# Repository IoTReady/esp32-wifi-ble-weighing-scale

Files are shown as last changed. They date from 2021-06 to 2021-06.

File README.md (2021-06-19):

# ESP32 Weighing Scale

This is a weighing scale designed to share data over Wi-Fi using esp32 WROOM32 module.
For the weighing scale we are using a load cell and measuring the output using a HX711 24-bit ADC designed for weigh scales and industrial control applications to interface directly with a bridge sensor.

The final design and gerber files are available [here](https://github.com/IoTReady/esp32-wifi-ble-weighing-scale/blob/master/design/Single_scale_v3_kicad/single_scale_v3_gerber.zip).

# Circuit Design
## Power Supply
We are using a 3.7V Li-Ion battery for powering this scale. The current rating can be changed depending on the use case. We also have a battery charging circuit on the board, so you don't have to remove the battery for charging it.

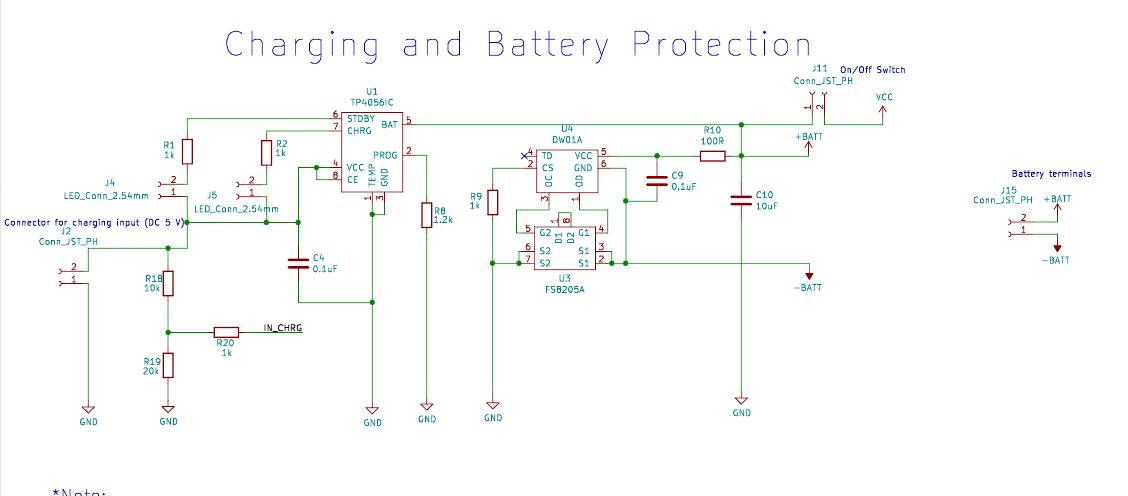
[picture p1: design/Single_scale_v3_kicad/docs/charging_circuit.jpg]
charging circuit Battery Charging Circuit


We use a TP4056 charging IC, as it is easily available and gives a reasonable 1000 mA output current, with 4.2V output voltage for charging the battery. For preventing the battery from over-charging and over-discharging, we use the DW01A protection IC. It is connected with a FS8205A switch IC, which will cut off the battery from the circuit if any fault is detected.

Finally, the 3.7V battery ouput is fed to two voltage regulators to get +5V and +3.3V output voltages as shown below:

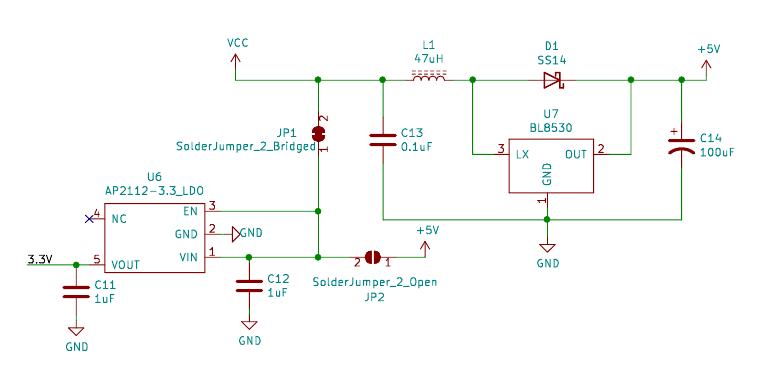
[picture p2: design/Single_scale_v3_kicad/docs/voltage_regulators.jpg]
voltage regs Voltage Regulators


## ADC Circuit
We are using HX711 24-bit ADC IC for converting the analog data from the Load cell. We selected HX711 as it is designed specifically for weighing scales, to interface with brige sensors directly. Load cells are basically bridge sensors.
As shown below the final output is in serial data output form. This is basically a UART output, and there are few digital pin controls.

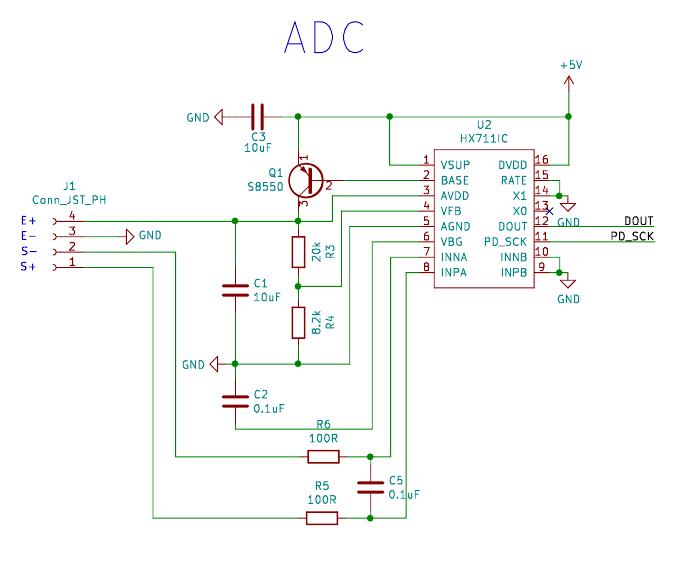
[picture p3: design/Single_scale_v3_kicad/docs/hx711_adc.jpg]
adc HX711 ADC


## ESP32
The brains of our weighing scale, the esp32 wroom32 module is a BLE plus WiFi SoC which collects weight data from the ADC circuit and outputs the final processed data via a digital display and WiFi to the selected servers for maintaing inventories or doing any data analysis.

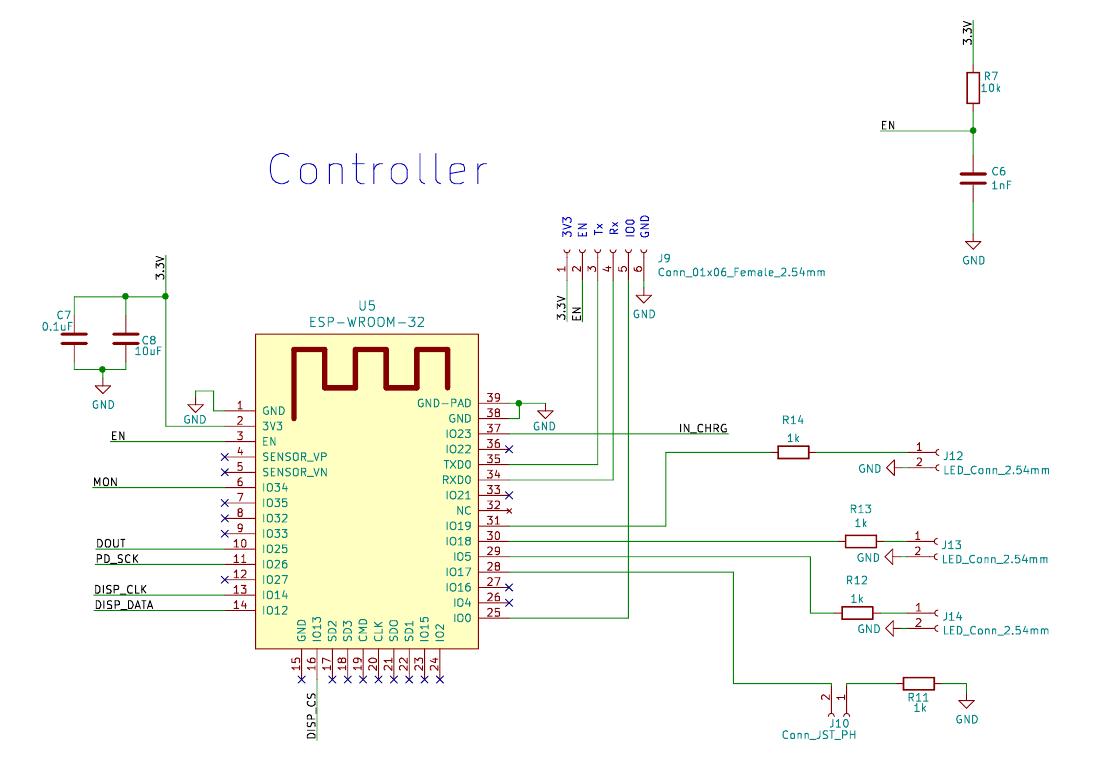
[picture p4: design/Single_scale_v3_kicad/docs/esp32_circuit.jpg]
esp32


# PCB
This is what the final PCB looks like:

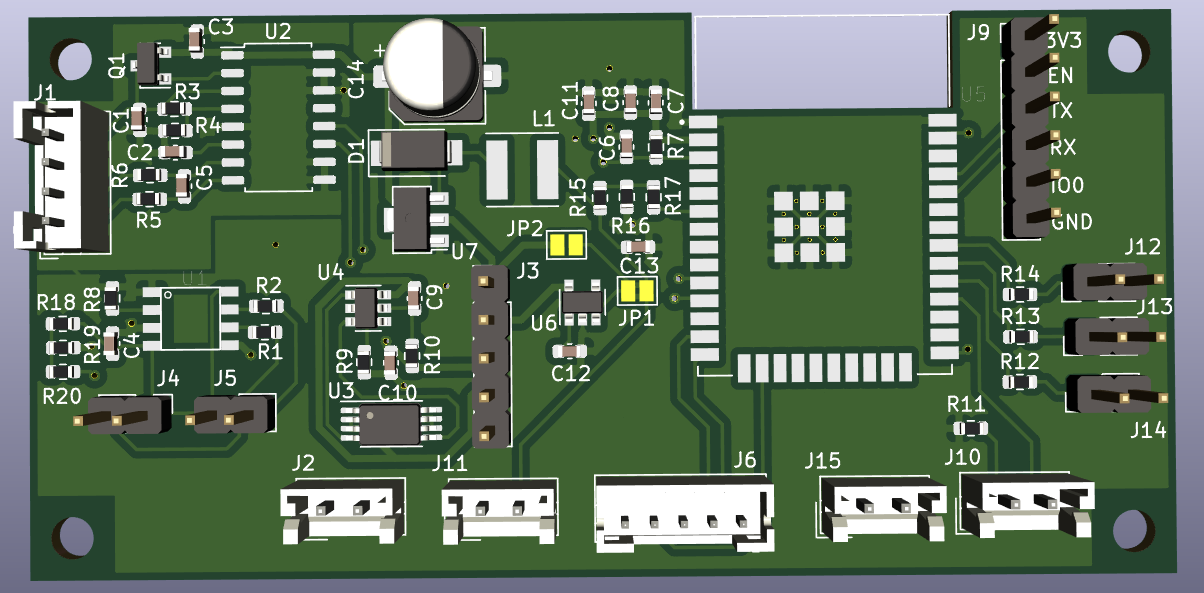
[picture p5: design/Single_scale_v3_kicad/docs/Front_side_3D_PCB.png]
pcb_front


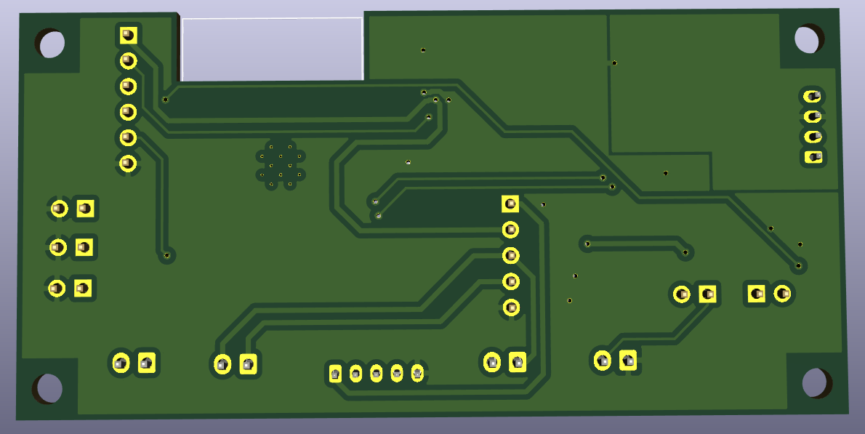
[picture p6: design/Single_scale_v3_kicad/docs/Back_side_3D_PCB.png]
pcb_back


# Firmware

## Features
- 24 bit HX711 as ADC
- Any 4 wire load cell
- BLE communication
- Tare button
- Battery level monitor
- MAX7219 driven 7-segment display
- OTA (to be hosted from local network)
- Console setting of tare value and sensor calibration

### Weight Calculation
The HX711 is a great match for weighing use-cases. The 24 bit ADC is designed specifically for weight measurements and is directly interfaceable with load sensors and weigh bridges. There is no programming needed for the internal registers. All controls to the HX711 are through the pins. The HX711 component handles everything necessary for conversion to calibration. For more details, find the HX711 datasheet [here](https://cdn.sparkfun.com/datasheets/Sensors/ForceFlex/hx711_english.pdf)

### Factors for weight calculation/conversion
There are two major factors to consider in order to get an accurate calculation:
1. Tare Value (OFFSET): In weighment applications it is important to be able to reset the output value to zero if and when needed. In the firmware however, it is particularly important to understand the ADC output at zero. Any value higher or lower than this ADC value would result in positive or negative weight hereafter. Almost all weighing scales will provide a button for the users to return the current weight to zero. This is used to round off any extra weight that needs not be accounted, for example the container. In this application, the tare button has been assigned to GPIO19 on the ESP32.
  The auto-tare feature in the application tares the system at startup, such that the weighing scale always starts with a zero value. This eliminates human error. Make sure that there are no items placed on the platform and even the bottom of the scale is not in contact with any object at the time of starting up the machine until the display shows 0.
  
3. Calibration value (SCALE): The calibration value is the multiplication factor that needs to be multiplied to the ADC output value in order to get the real-time weight out of it in the units needed. This calibration value will be different for all individual load cells, hence it is important that all weighing machines go through a calibration procedure before they are shipped.

This application provides a simple method to set/calculate the above mentioned Tare and Calibration values:
- Start by placing the scale in a stable platform and environment. Please choose an area with minimum air currents and vibration levels.
- Connect your computer to the ESP32 controller's UART0 using an FTDI connector.
- You will need software to access the serial communication happening over the UART lines. For example, [PuTTY](https://www.putty.org/).
- While the program is flashed and running on the ESP32, press 'm' and hit Enter. You will be provided a menu using which you can access the tare and calibration features.
- For calibration, carry out the following steps:
  - You need to select a test value weight. This weight must be within the scale constraint and approximately 50% of the upper capacity. This should also be a known weight that you should possess.
  - Make sure that there are no items placed on the platform and even the bottom of the scale is not in contact with any object.
  - Make sure the console shows 0 weight. If not, press the tare button so the console shows 0.
  - Place the known selected weight on the platform of the weighing scale and view the weight on the console.
  - Follow the instructions to either change the calibration value or select the current selected calibration value if the weight shown on console is correct.
  - Repeat until the weight is correct.
  - Save

### BLE Characteristics:
| Service / Characteristics Name | UUID Handle | Properties | Description |
|---|---|---|---|
| Device State Service | 000000ff-0000-1000-8000-00805f9b34fb | Service | - |
| Weight Data | 0000ff00-0000-1000-8000-00805f9b34fb | Read | Weight in kgs |

| Service / Characteristics Name  | UUID Handle | Properties  | Description | Size | Data Type |
|---|---|---|---|---|---|
| System Settings Service | 000000ee-0000-1000-8000-00805f9b34fb | Service | - | - | - |
| Device ID Characteristic | 0000ee00-0000-1000-8000-00805f9b34fb | Read | Read Device ID | Length: 12 | String |
| WiFi SSID  Characteristic | 0000ee01-0000-1000-8000-00805f9b34fb | Read/Write  | WiFi SSID configured with the device | Max Length: 32  | String |
| WiFi Password Characteristic | 0000ee02-0000-1000-8000-00805f9b34fb | Read/Write  | WiFi Password configured with the device | Max Length: 32  | String |
| OTA IP Characteristic | 0000ee03-0000-1000-8000-00805f9b34fb | Read/Write  | Read/Write the IP of OTA host | Max Length: 100 | String |
| OTA Port Characteristic | 0000ee04-0000-1000-8000-00805f9b34fb | Read/Write  | Read/Write the Port of OTA host server | Max Length: 100 | String |
| OTA Filename Characteristic | 0000ee05-0000-1000-8000-00805f9b34fb | Read/Write  | Read/Write the filename of OTA binary file | Max Length: 100 | String |
| Force OTA Characteristic | 0000ee06-0000-1000-8000-00805f9b34fb | Write | Initiate OTA procedure Value: ‘1’ [0x31] | 1 byte | Unsigned Integer |
| Tare Weight Characteristic | 0000ee07-0000-1000-8000-00805f9b34fb | Write | Cancel OTA procedure within 10 seconds of initiation Value: ‘1’ [0x31] | 1 byte | Unsigned Integer |
| Connect WiFi Characteristic | 0000ee08-0000-1000-8000-00805f9b34fb | Write | Connect to previously configured WiFi credentials. Value: ‘1’ [0x31] | 1 byte | Unsigned Integer |
| Software Version Characteristic | 0000ee09-0000-1000-8000-00805f9b34fb | Read | Read the Software Version in the device | - | String |
# Applications
This weighing scale is designed keeping in mind sharing of data over the internet. So, any application where we need to capture weight of things and maintain a record for any use, we can integrate this device in that system.

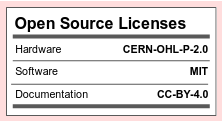
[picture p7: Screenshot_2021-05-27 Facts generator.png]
license_info


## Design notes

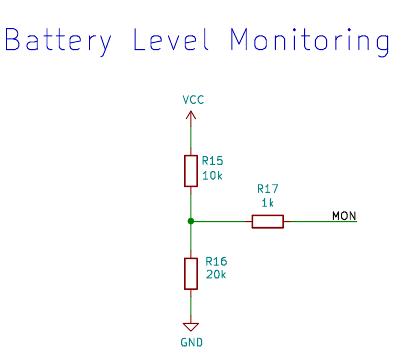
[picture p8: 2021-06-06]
design/Single_scale_v3_kicad/docs/battery_monitor.jpg

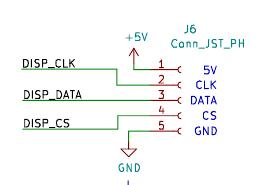
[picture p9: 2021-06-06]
design/Single_scale_v3_kicad/docs/display_connector.jpg

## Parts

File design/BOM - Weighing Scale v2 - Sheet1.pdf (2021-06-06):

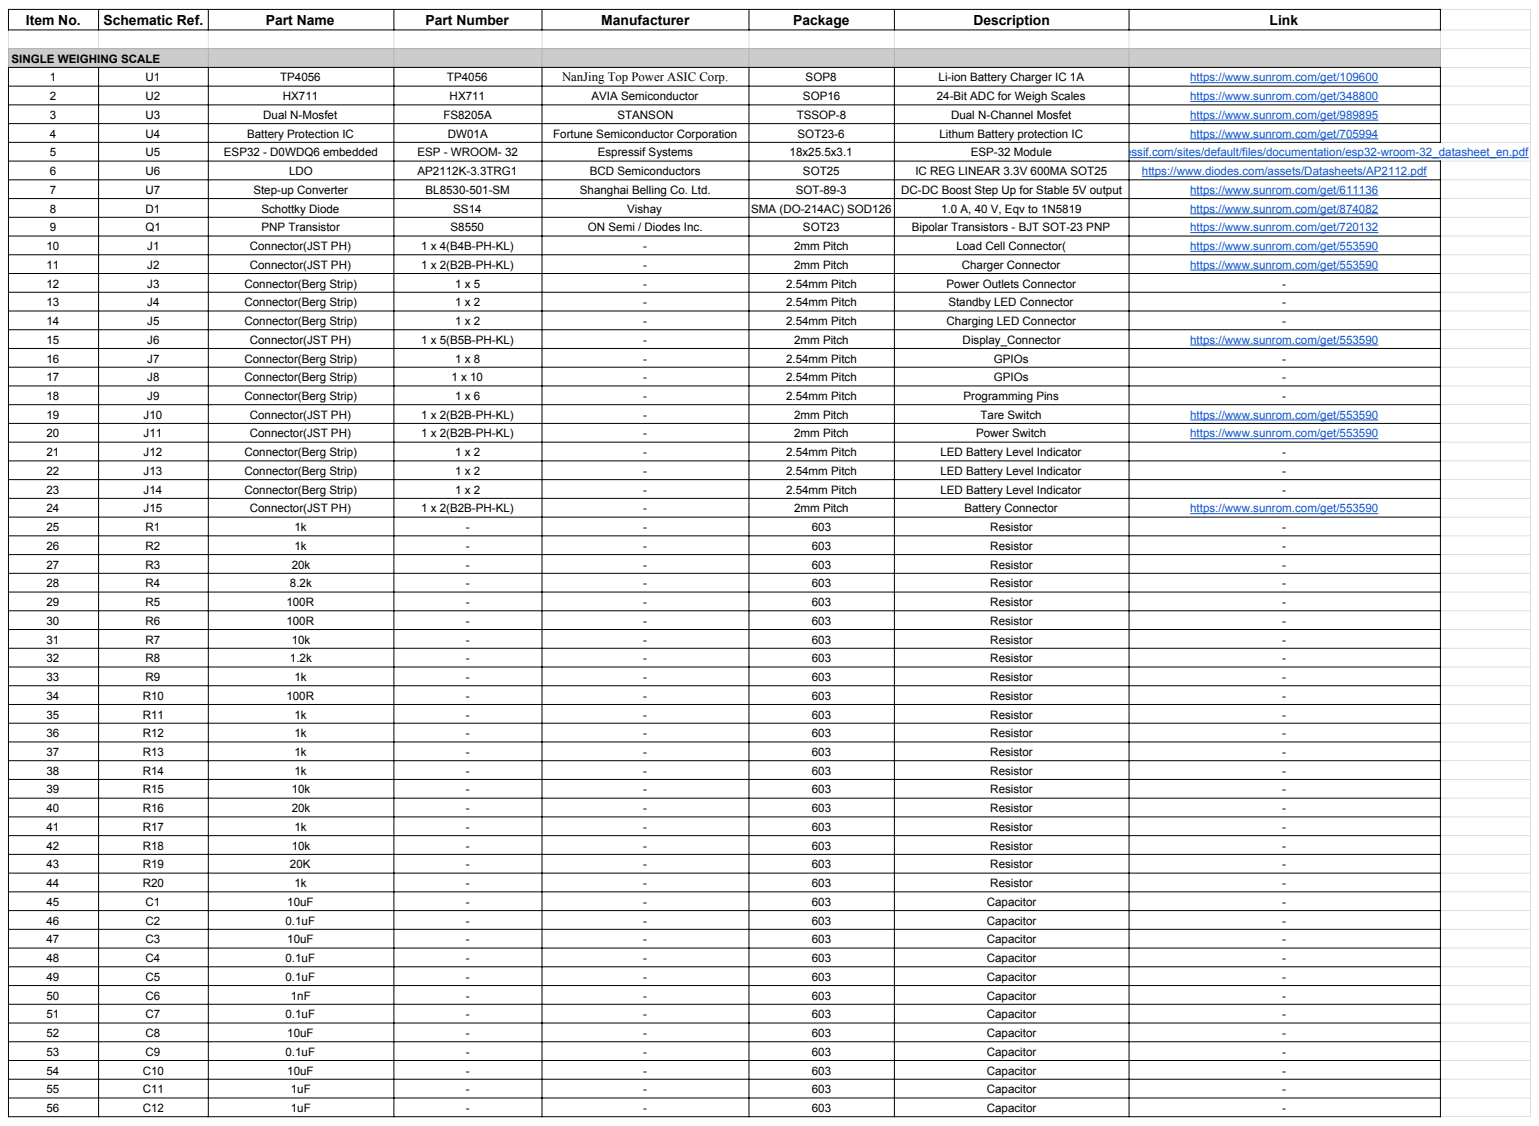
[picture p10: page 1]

1 | U1 | TP4056 | TP4056 | NanJing Top Power ASIC Corp. | SOP8 | Li-ion Battery Charger IC 1A | https://www.sunrom.com/get/109600
2 | U2 | HX711 | HX711 | AVIA Semiconductor | SOP16 | 24-Bit ADC for Weigh Scales | https://www.sunrom.com/get/348800
3 | U3 | Dual N-Mosfet | FS8205A | STANSON | TSSOP-8 | Dual N-Channel Mosfet | https://www.sunrom.com/get/989895
4 | U4 | Battery Protection IC | DW01A | Fortune Semiconductor Corporation | SOT23-6 | Lithum Battery protection IC | https://www.sunrom.com/get/705994

6 | U6 | LDO | AP2112K-3.3TRG1 | BCD Semiconductors | SOT25 | IC REG LINEAR 3.3V 600MA SOT25 | https://www.diodes.com/assets/Datasheets/AP2112.pdf
7 | U7 | Step-up Converter | BL8530-501-SM | Shanghai Belling Co. Ltd. | SOT-89-3 | DC-DC Boost Step Up for Stable 5V output | https://www.sunrom.com/get/611136
8 | D1 | Schottky Diode | SS14 | Vishay | SMA (DO-214AC) SOD126 | 1.0 A, 40 V, Eqv to 1N5819 | https://www.sunrom.com/get/874082
9 | Q1 | PNP Transistor | S8550 | ON Semi / Diodes Inc. | SOT23 | Bipolar Transistors - BJT SOT-23 PNP | https://www.sunrom.com/get/720132
10 | J1 | Connector(JST PH) | 1 x 4(B4B-PH-KL) | - | 2mm Pitch | Load Cell Connector( | https://www.sunrom.com/get/553590
11 | J2 | Connector(JST PH) | 1 x 2(B2B-PH-KL) | - | 2mm Pitch | Charger Connector | https://www.sunrom.com/get/553590
12 | J3 | Connector(Berg Strip) | 1 x 5 | - | 2.54mm Pitch | Power Outlets Connector | -
13 | J4 | Connector(Berg Strip) | 1 x 2 | - | 2.54mm Pitch | Standby LED Connector | -
14 | J5 | Connector(Berg Strip) | 1 x 2 | - | 2.54mm Pitch | Charging LED Connector | -
15 | J6 | Connector(JST PH) | 1 x 5(B5B-PH-KL) | - | 2mm Pitch | Display_Connector | https://www.sunrom.com/get/553590
16 | J7 | Connector(Berg Strip) | 1 x 8 | - | 2.54mm Pitch | GPIOs | -
17 | J8 | Connector(Berg Strip) | 1 x 10 | - | 2.54mm Pitch | GPIOs | -
18 | J9 | Connector(Berg Strip) | 1 x 6 | - | 2.54mm Pitch | Programming Pins | -
19 | J10 | Connector(JST PH) | 1 x 2(B2B-PH-KL) | - | 2mm Pitch | Tare Switch | https://www.sunrom.com/get/553590
20 | J11 | Connector(JST PH) | 1 x 2(B2B-PH-KL) | - | 2mm Pitch | Power Switch | https://www.sunrom.com/get/553590
21 | J12 | Connector(Berg Strip) | 1 x 2 | - | 2.54mm Pitch | LED Battery Level Indicator | -
22 | J13 | Connector(Berg Strip) | 1 x 2 | - | 2.54mm Pitch | LED Battery Level Indicator | -
23 | J14 | Connector(Berg Strip) | 1 x 2 | - | 2.54mm Pitch | LED Battery Level Indicator | -
24 | J15 | Connector(JST PH) | 1 x 2(B2B-PH-KL) | - | 2mm Pitch | Battery Connector | https://www.sunrom.com/get/553590
25 | R1 | 1k | - | - | 603 | Resistor | -
26 | R2 | 1k | - | - | 603 | Resistor | -
27 | R3 | 20k | - | - | 603 | Resistor | -
28 | R4 | 8.2k | - | - | 603 | Resistor | -
29 | R5 | 100R | - | - | 603 | Resistor | -
30 | R6 | 100R | - | - | 603 | Resistor | -
31 | R7 | 10k | - | - | 603 | Resistor | -
32 | R8 | 1.2k | - | - | 603 | Resistor | -
33 | R9 | 1k | - | - | 603 | Resistor | -
34 | R10 | 100R | - | - | 603 | Resistor | -
35 | R11 | 1k | - | - | 603 | Resistor | -
36 | R12 | 1k | - | - | 603 | Resistor | -
37 | R13 | 1k | - | - | 603 | Resistor | -
38 | R14 | 1k | - | - | 603 | Resistor | -
39 | R15 | 10k | - | - | 603 | Resistor | -
40 | R16 | 20k | - | - | 603 | Resistor | -
41 | R17 | 1k | - | - | 603 | Resistor | -
42 | R18 | 10k | - | - | 603 | Resistor | -
43 | R19 | 20K | - | - | 603 | Resistor | -
44 | R20 | 1k | - | - | 603 | Resistor | -
45 | C1 | 10uF | - | - | 603 | Capacitor | -
46 | C2 | 0.1uF | - | - | 603 | Capacitor | -
47 | C3 | 10uF | - | - | 603 | Capacitor | -
48 | C4 | 0.1uF | - | - | 603 | Capacitor | -
49 | C5 | 0.1uF | - | - | 603 | Capacitor | -
50 | C6 | 1nF | - | - | 603 | Capacitor | -
51 | C7 | 0.1uF | - | - | 603 | Capacitor | -
52 | C8 | 10uF | - | - | 603 | Capacitor | -
53 | C9 | 0.1uF | - | - | 603 | Capacitor | -
54 | C10 | 10uF | - | - | 603 | Capacitor | -
55 | C11 | 1uF | - | - | 603 | Capacitor | -
56 | C12 | 1uF | - | - | 603 | Capacitor | -

57 | C13 | 0.1uF | - | - | 603 | Capacitor | -
58 | C14 | 100uF | - | - | 6.3x5.4mm SMD | Aluminium Capacitor | https://www.sunrom.com/get/215444
59 | L1 | 47uH | - | - | 5mm SMD | Wirewound SMD Inductor | https://www.sunrom.com/get/797000
60 | JP1 | SolderJumper_2_Bridged | - | - | - Solder Bridge(Closed) | | -
61 | JP2 | SolderJumper_2_Open | - | - | - Solder Bridge(Open) | | -

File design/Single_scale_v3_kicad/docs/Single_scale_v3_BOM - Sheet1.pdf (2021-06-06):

Sl.no | Reference | Value | Package | Link | Quantity
1 | C1, C3, C8, C10 | 10uF | Capacitor_SMD:C_0603_1608Metric | ~ | 4
2 | C2, C4, C5, C7, C9, C13 | 0.1uF | Capacitor_SMD:C_0603_1608Metric | ~ | 6
3 | C6 | 1nF | Capacitor_SMD:C_0603_1608Metric | ~ | 1
4 | C11, C12 | 1uF | Capacitor_SMD:C_0603_1608Metric | ~ | 2
5 | C14 | 100uF | Capacitor_SMD:CP_Elec_6.3x5.4 | ~ | 1
6 | D1 | SS14 | Diode_SMD:D_SMA | ~ | 1
7 | J1 | Conn_JST_PH | Connector_JST:JST_PH_B4B-PH-K_1x04_P2.00mm_Vertical | ~ | 1
8 | J2, J10, J11, J15 | Conn_JST_PH | Connector_JST:JST_EH_B2B-EH-A_1x02_P2.50mm_Vertical | ~ | 4
9 | J3 | Conn_01x5_Female_2.54mm | Connector_PinHeader_2.54mm:PinHeader_1x05_P2.54mm_Vertical | ~ | 1
10 | J6 | Conn_JST_PH | Connector_JST:JST_PH_B5B-PH-K_1x05_P2.00mm_Vertical | ~ | 1
11 | J9 | Conn_01x06_Female_2.54mm | Connector_PinHeader_2.54mm:PinHeader_1x06_P2.54mm_Vertical | ~ | 1
12 | J4, J5, J12-J14 | LED_Conn_2.54mm | Connector_PinHeader_2.54mm:PinHeader_1x02_P2.54mm_Vertical | ~ | 5
13 | JP1 | SolderJumper_2_Bridged | Jumper:SolderJumper-2_P1.3mm_Bridged2Bar_Pad1.0x1.5mm | ~ | 1
14 | JP2 | SolderJumper_2_Open | Jumper:SolderJumper-2_P1.3mm_Open_Pad1.0x1.5mm | ~ | 1
15 | L1 | 47uH | Inductor_SMD:L_Taiyo-Yuden_MD-5050 | ~ | 1
16 | Q1 | S8550 | single_scale:SOT-23_modified | | 1
17 | R3, R16, R19 | 20k | Resistor_SMD:R_0603_1608Metric | ~ | 3
18 | R4 | 8.2k | Resistor_SMD:R_0603_1608Metric | ~ | 1
19 | R5, R6, R10 | 100R | Resistor_SMD:R_0603_1608Metric | ~ | 3
20 | R7, R15, R18 | 10k | Resistor_SMD:R_0603_1608Metric | ~ | 3
21 | R8 | 1.2k | Resistor_SMD:R_0603_1608Metric | ~ | 1
22 | R1, R2, R9, R11-R14, R17, R20 | 1k | Resistor_SMD:R_0603_1608Metric | ~ | 9
23 | U1 | TP4056IC | single_scale:SOP-8 | | 1
24 | U2 | HX711IC | Package_SO:SOP-16_4.55x10.3mm_P1.27mm | | 1
25 | U3 | FS8205A | Package_SO:TSSOP-8_4.4x3mm_P0.65mm | | 1
26 | U4 | DW01A | Package_TO_SOT_SMD:SOT-23-6 | | 1
27 | U5 | ESP-WROOM-32 | single_scale:MODULE_ESP32-WROOM-32 | | 1
28 | U6 | AP2112-3.3_LDO | Package_TO_SOT_SMD:SOT-23-5 | | 1
29 | U7 | BL8530 | Package_TO_SOT_SMD:SOT-89-3 | | 1

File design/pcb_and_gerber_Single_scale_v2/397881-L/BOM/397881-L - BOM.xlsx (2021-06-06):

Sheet: Sheet1
Item No. | Schematic Ref. | Part Name | Part Number | Manufacturer | Package | Description | Link | Remarks
SINGLE WEIGHING SCALE
1 | U1 | TP4056 | TP4056 | NanJing Top Power ASIC Corp. | SOP8 | Li-ion Battery Charger IC 1A | https://www.sunrom.com/get/109600, Or https://easyeda.com/editor#id=!71fd3f31f7a3ef00a5e0ec6cf54d61e0 | center pad is Not connected to any where ( EX-2 Reply)
2 | U2 | HX711 | HX711 | AVIA Semiconductor | SOP16 | 24-Bit ADC for Weigh Scales | https://www.sunrom.com/get/348800 | Ok as per reply5
3 | U3 | Dual N-Mosfet | FS8205A | STANSON | TSSOP-8 | Dual N-Channel Mosfet | https://www.sunrom.com/get/989895
4 | U4 | Battery Protection IC | DW01A | Fortune Semiconductor Corporation | SOT23-6 | Lithum Battery protection IC | https://www.sunrom.com/get/705994
5 | U5 | ESP32 - D0WDQ6 embedded | ESP - WROOM- 32 | Espressif Systems | 18x25.5x3.1 | ESP-32 Module | https://www.espressif.com/sites/default/files/documentation/esp32-wroom-32_datasheet_en.pdf
6 | U6 | LDO | AP2112K-3.3TRG1 | BCD Semiconductors | SOT25 | IC REG LINEAR 3.3V 600MA SOT25 | https://www.diodes.com/assets/Datasheets/AP2112.pdf
7 | U7 | Step-up Converter | BL8530-501-SM | Shanghai Belling Co. Ltd. | SOT-89-3 | DC-DC Boost Step Up for Stable 5V output | https://www.sunrom.com/get/611136
8 | D1 | Schottky Diode | SS14 | Vishay | SMA (DO-214AC) SOD126 | 1.0 A, 40 V, Eqv to 1N5819 | https://www.sunrom.com/get/874082
9 | Q1 | PNP Transistor | S8550 | ON Semi / Diodes Inc. | SOT23 | Bipolar Transistors - BJT SOT-23 PNP | https://www.sunrom.com/get/720132
10 | J1 | Connector(JST PH) | 1 x 4(S4B-PH-K-S(LF)(SN)) | JST PH connectors(right angle)--EX-3 Reply | 2mm Pitch | Load Cell Connector( | https://www.digikey.in/product-detail/en/jst-sales-america-inc/S2B-PH-K-S-LF-SN/455-1719-ND/926626
11 | J2 | Connector(JST PH) | 1 x 2(S2B-PH-K-S(LF)(SN)) | JST PH connectors(right angle)--EX-3 Reply | 2mm Pitch | Charger Connector | https://www.digikey.in/product-detail/en/jst-sales-america-inc/S2B-PH-K-S-LF-SN/455-1719-ND/926626
12 | J3 | Connector(Berg Strip) | 1 x 5 | - | 2.54mm Pitch | Power Outlets Connector | -
13 | J4 | Connector(Berg Strip) | 1 x 2 | - | 2.54mm Pitch | Standby LED Connector | -
14 | J5 | Connector(Berg Strip) | 1 x 2 | - | 2.54mm Pitch | Charging LED Connector | -
15 | J6 | Connector(JST PH) | 1 x 5(S5B-PH-K-S(LF)(SN)) | JST PH connectors(right angle)--EX-3 Reply | 2mm Pitch | Display_Connector | https://www.digikey.in/product-detail/en/jst-sales-america-inc/S2B-PH-K-S-LF-SN/455-1719-ND/926626
16 | J7 | Connector(Berg Strip) | 1 x 8 | EX-1 Reply | 2.54mm Pitch | GPIOs | -
17 | J8 | Connector(Berg Strip) | 1 x 10 | - | 2.54mm Pitch | GPIOs | -
18 | J9 | Connector(Berg Strip) | 1 x 6 | - | 2.54mm Pitch | Programming Pins | -
19 | J10 | Connector(JST PH) | 1 x 2(S2B-PH-K-S(LF)(SN)) | JST PH connectors(right angle)--EX-3 Reply | 2mm Pitch | Tare Switch | https://www.digikey.in/product-detail/en/jst-sales-america-inc/S2B-PH-K-S-LF-SN/455-1719-ND/926626
20 | J11 | Connector(JST PH) | 1 x 2(S2B-PH-K-S(LF)(SN)) | JST PH connectors(right angle)--EX-3 Reply | 2mm Pitch | Power Switch | https://www.digikey.in/product-detail/en/jst-sales-america-inc/S2B-PH-K-S-LF-SN/455-1719-ND/926626
21 | J12 | Connector(Berg Strip) | 1 x 2 | - | 2.54mm Pitch | LED Battery Level Indicator | -
22 | J13 | Connector(Berg Strip) | 1 x 2 | - | 2.54mm Pitch | LED Battery Level Indicator | -
23 | J14 | Connector(Berg Strip) | 1 x 2 | - | 2.54mm Pitch | LED Battery Level Indicator
24 | J15 | Connector(JST PH) | 1 x 2(S2B-PH-K-S(LF)(SN)) | JST PH connectors(right angle)--EX-3 Reply | 2mm Pitch | Battery Connector | https://www.digikey.in/product-detail/en/jst-sales-america-inc/S2B-PH-K-S-LF-SN/455-1719-ND/926626
25 | R1 | 1k | - | - | 603 | Resistor | -
26 | R2 | 1k | - | - | 603 | Resistor | -
27 | R3 | what's new around me | - | - | 603 | Resistor | -
28 | R4 | 8.2k | - | - | 603 | Resistor | -
29 | R5 | 100R | - | - | 603 | Resistor | -
30 | R6 | 100R | - | - | 603 | Resistor | -
31 | R7 | 10k | - | - | 603 | Resistor | -
32 | R8 | 1.2k | - | - | 603 | Resistor | -
33 | R9 | 1k | - | - | 603 | Resistor | -
34 | R10 | 100R | - | - | 603 | Resistor | -
35 | R11 | 1k | - | - | 603 | Resistor | -
36 | R12 | 1k | - | - | 603 | Resistor | -
37 | R13 | 1k | - | - | 603 | Resistor | -
38 | R14 | 1k | - | - | 603 | Resistor | -
39 | R15 | 10k | - | - | 603 | Resistor | -
40 | R16 | 20k | - | - | 603 | Resistor | -
41 | R17 | 1k | - | - | 603 | Resistor | -
42 | R18 | 10k | - | - | 603 | Resistor | -
43 | R19 | 20K | - | - | 603 | Resistor | -
44 | R20 | 1k | - | - | 603 | Resistor | -
45 | C1 | 10uF | - | - | 603 | Capacitor | -
46 | C2 | 0.1uF | - | - | 603 | Capacitor | -
47 | C3 | 10uF | - | - | 603 | Capacitor | -
48 | C4 | 0.1uF | - | - | 603 | Capacitor | -
49 | C5 | 0.1uF | - | - | 603 | Capacitor | -
50 | C6 | 1nF | - | - | 603 | Capacitor | -
51 | C7 | 0.1uF | - | - | 603 | Capacitor | -
52 | C8 | 10uF | - | - | 603 | Capacitor | -
53 | C9 | 0.1uF | - | - | 603 | Capacitor | -
54 | C10 | 10uF | - | - | 603 | Capacitor | -
55 | C11 | 1uF | - | - | 603 | Capacitor | -
56 | C12 | 1uF | - | - | 603 | Capacitor | -
57 | C13 | 0.1uF | - | - | 603 | Capacitor | -
58 | C14 | 100uF | - | - | 6.3x5.4mm SMD | Aluminium Capacitor | https://www.sunrom.com/get/215444
59 | L1 | 47uH | - | - | 5mm SMD | Wirewound SMD Inductor | https://www.sunrom.com/get/797000
60 | R21 |  | - | EX-1 Reply | 603 |  | -
61 | R22 |  | - | EX-1 Reply | 603 |  | -

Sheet: Quantity
Part Name | Qty / Board | Purchase (Y/N)
TP4056 | 1 | Sunrom
HX711 | 1 | Sunrom
Dual N-Mosfet | 1 | Sunrom
Battery Protection IC | 1 | Sunrom
ESP32 - D0WDQ6 embedded | 1 | Y
LDO | 1 | N
Step-up Converter | 1 | Sunrom
Schottky Diode | 1 | Sunrom
PNP Transistor | 1 | N
1k | 7 | TBD
20k | 1 | TBD
8.2k | 1 | TBD
100R | 3 | TBD
10k | 4 | TBD
1.2k | 1 | TBD
10uF | 4 | TBD
0.1uF | 5 | TBD
1nF | 1 | TBD
1uF | 2 | TBD
100uF | 1 | Sunrom
100uF (TANTALUM) | 1 | Sunrom
22uH | 1 | Sunrom

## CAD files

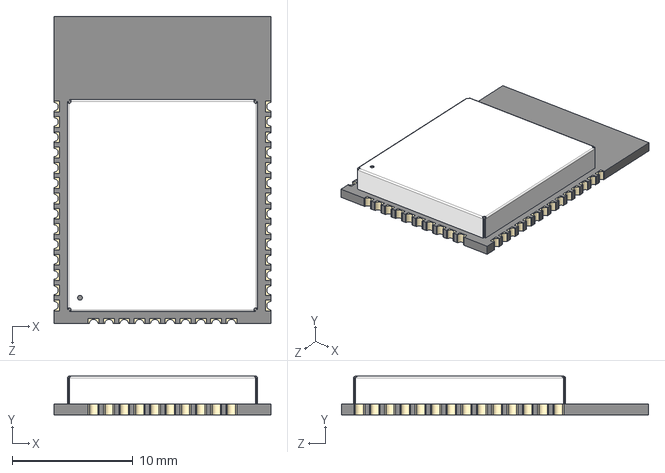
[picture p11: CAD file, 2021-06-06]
design/Single_scale_v3_kicad/kicad.lib/ESP32-WROOM-32.step
18.0 x 3.20 x 25.5 mm

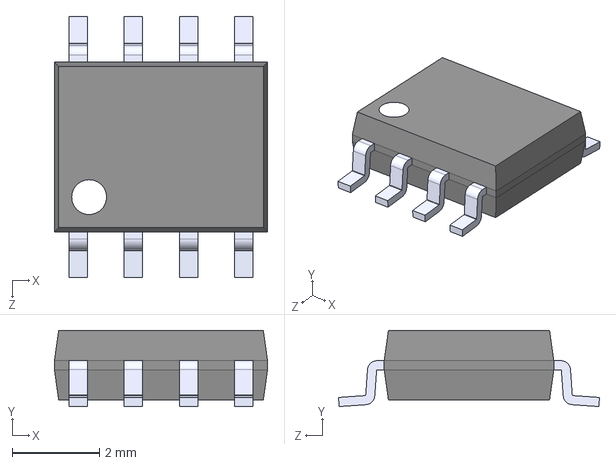
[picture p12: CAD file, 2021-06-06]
design/Single_scale_v3_kicad/kicad.lib/TP4056.step
4.90 x 1.75 x 6.00 mm

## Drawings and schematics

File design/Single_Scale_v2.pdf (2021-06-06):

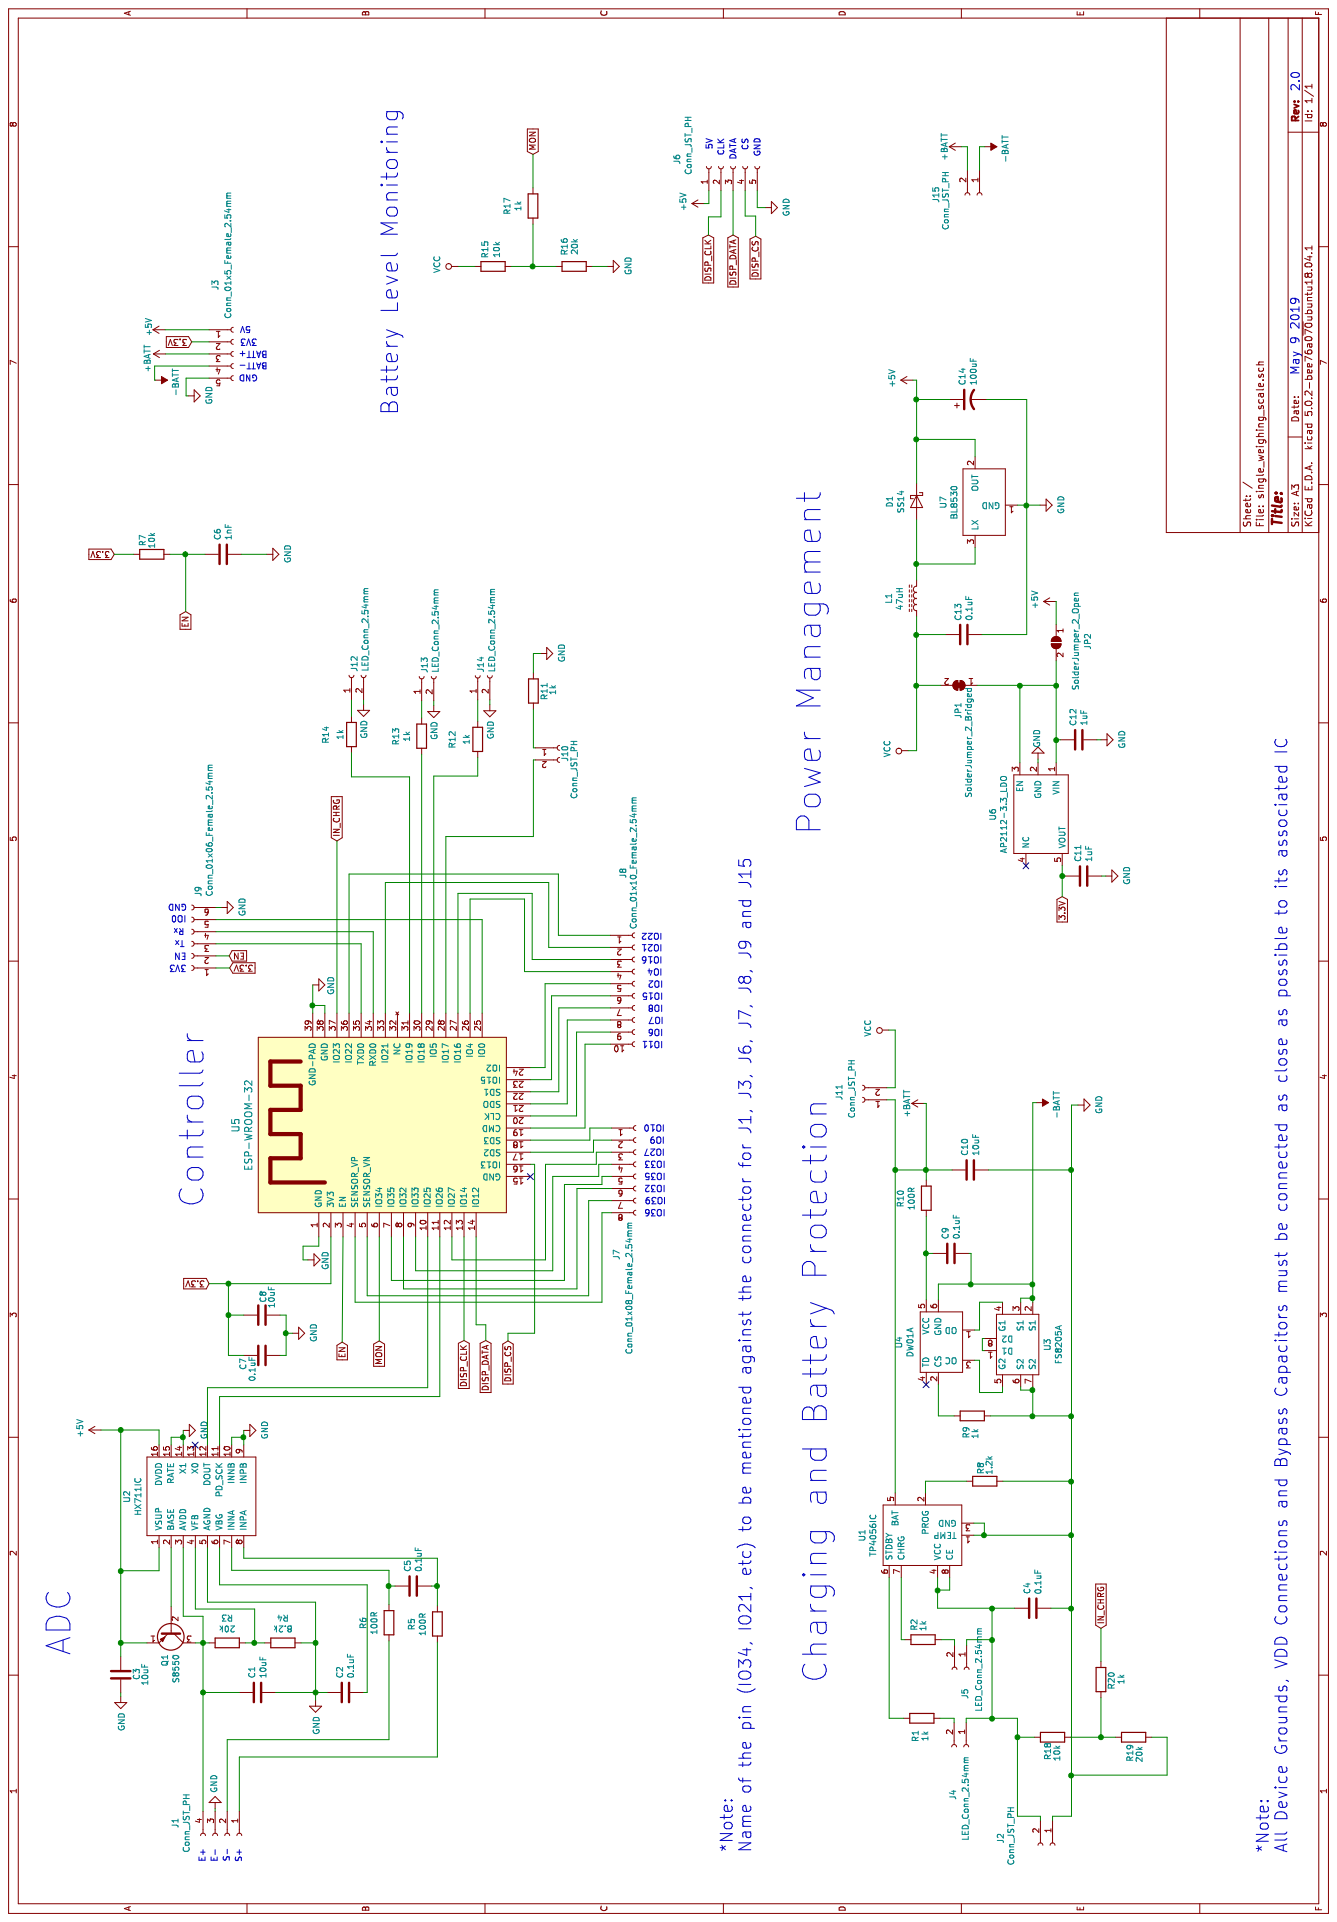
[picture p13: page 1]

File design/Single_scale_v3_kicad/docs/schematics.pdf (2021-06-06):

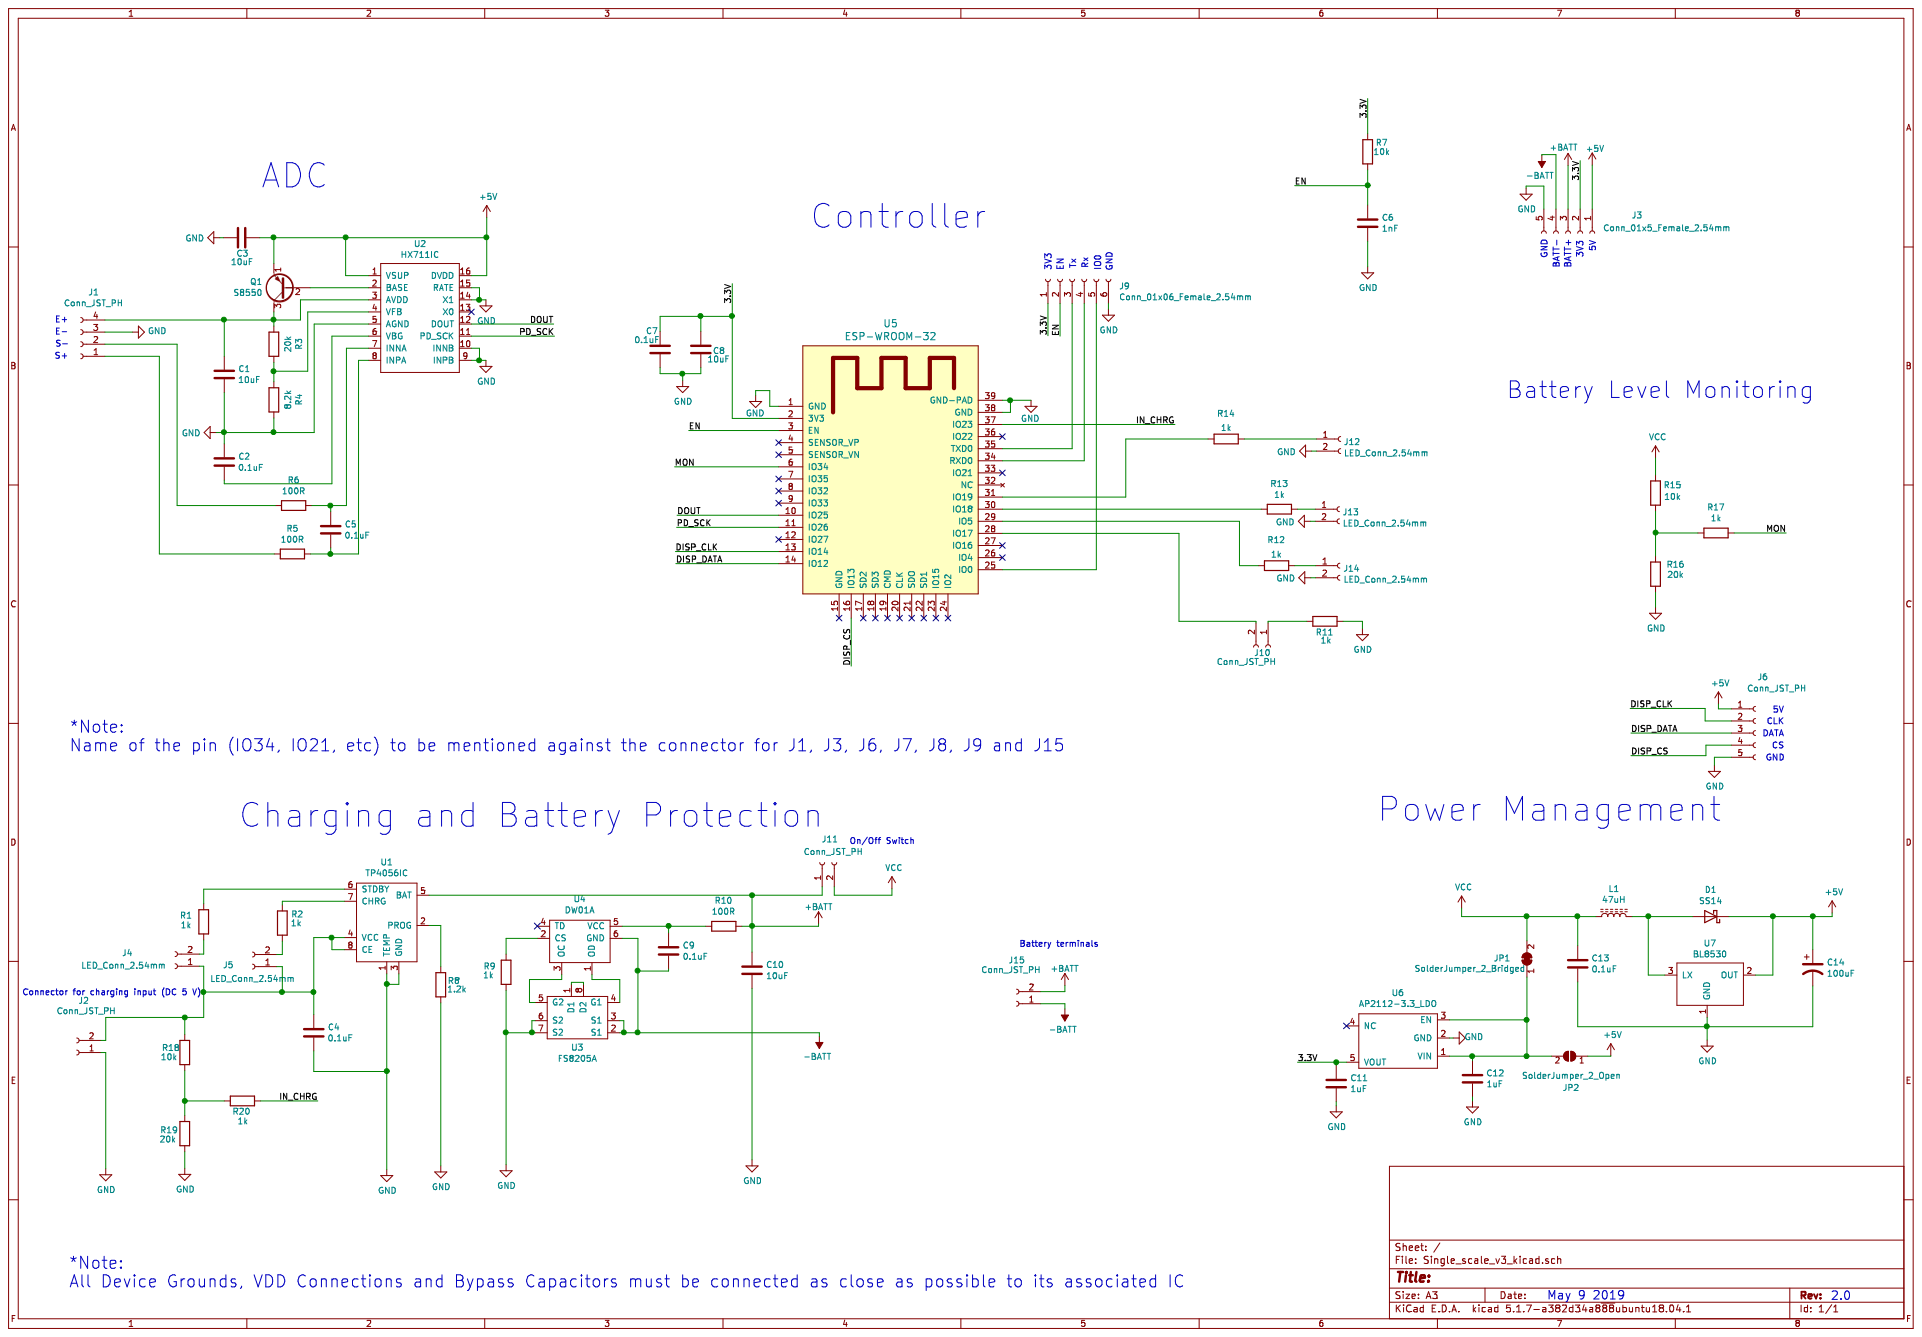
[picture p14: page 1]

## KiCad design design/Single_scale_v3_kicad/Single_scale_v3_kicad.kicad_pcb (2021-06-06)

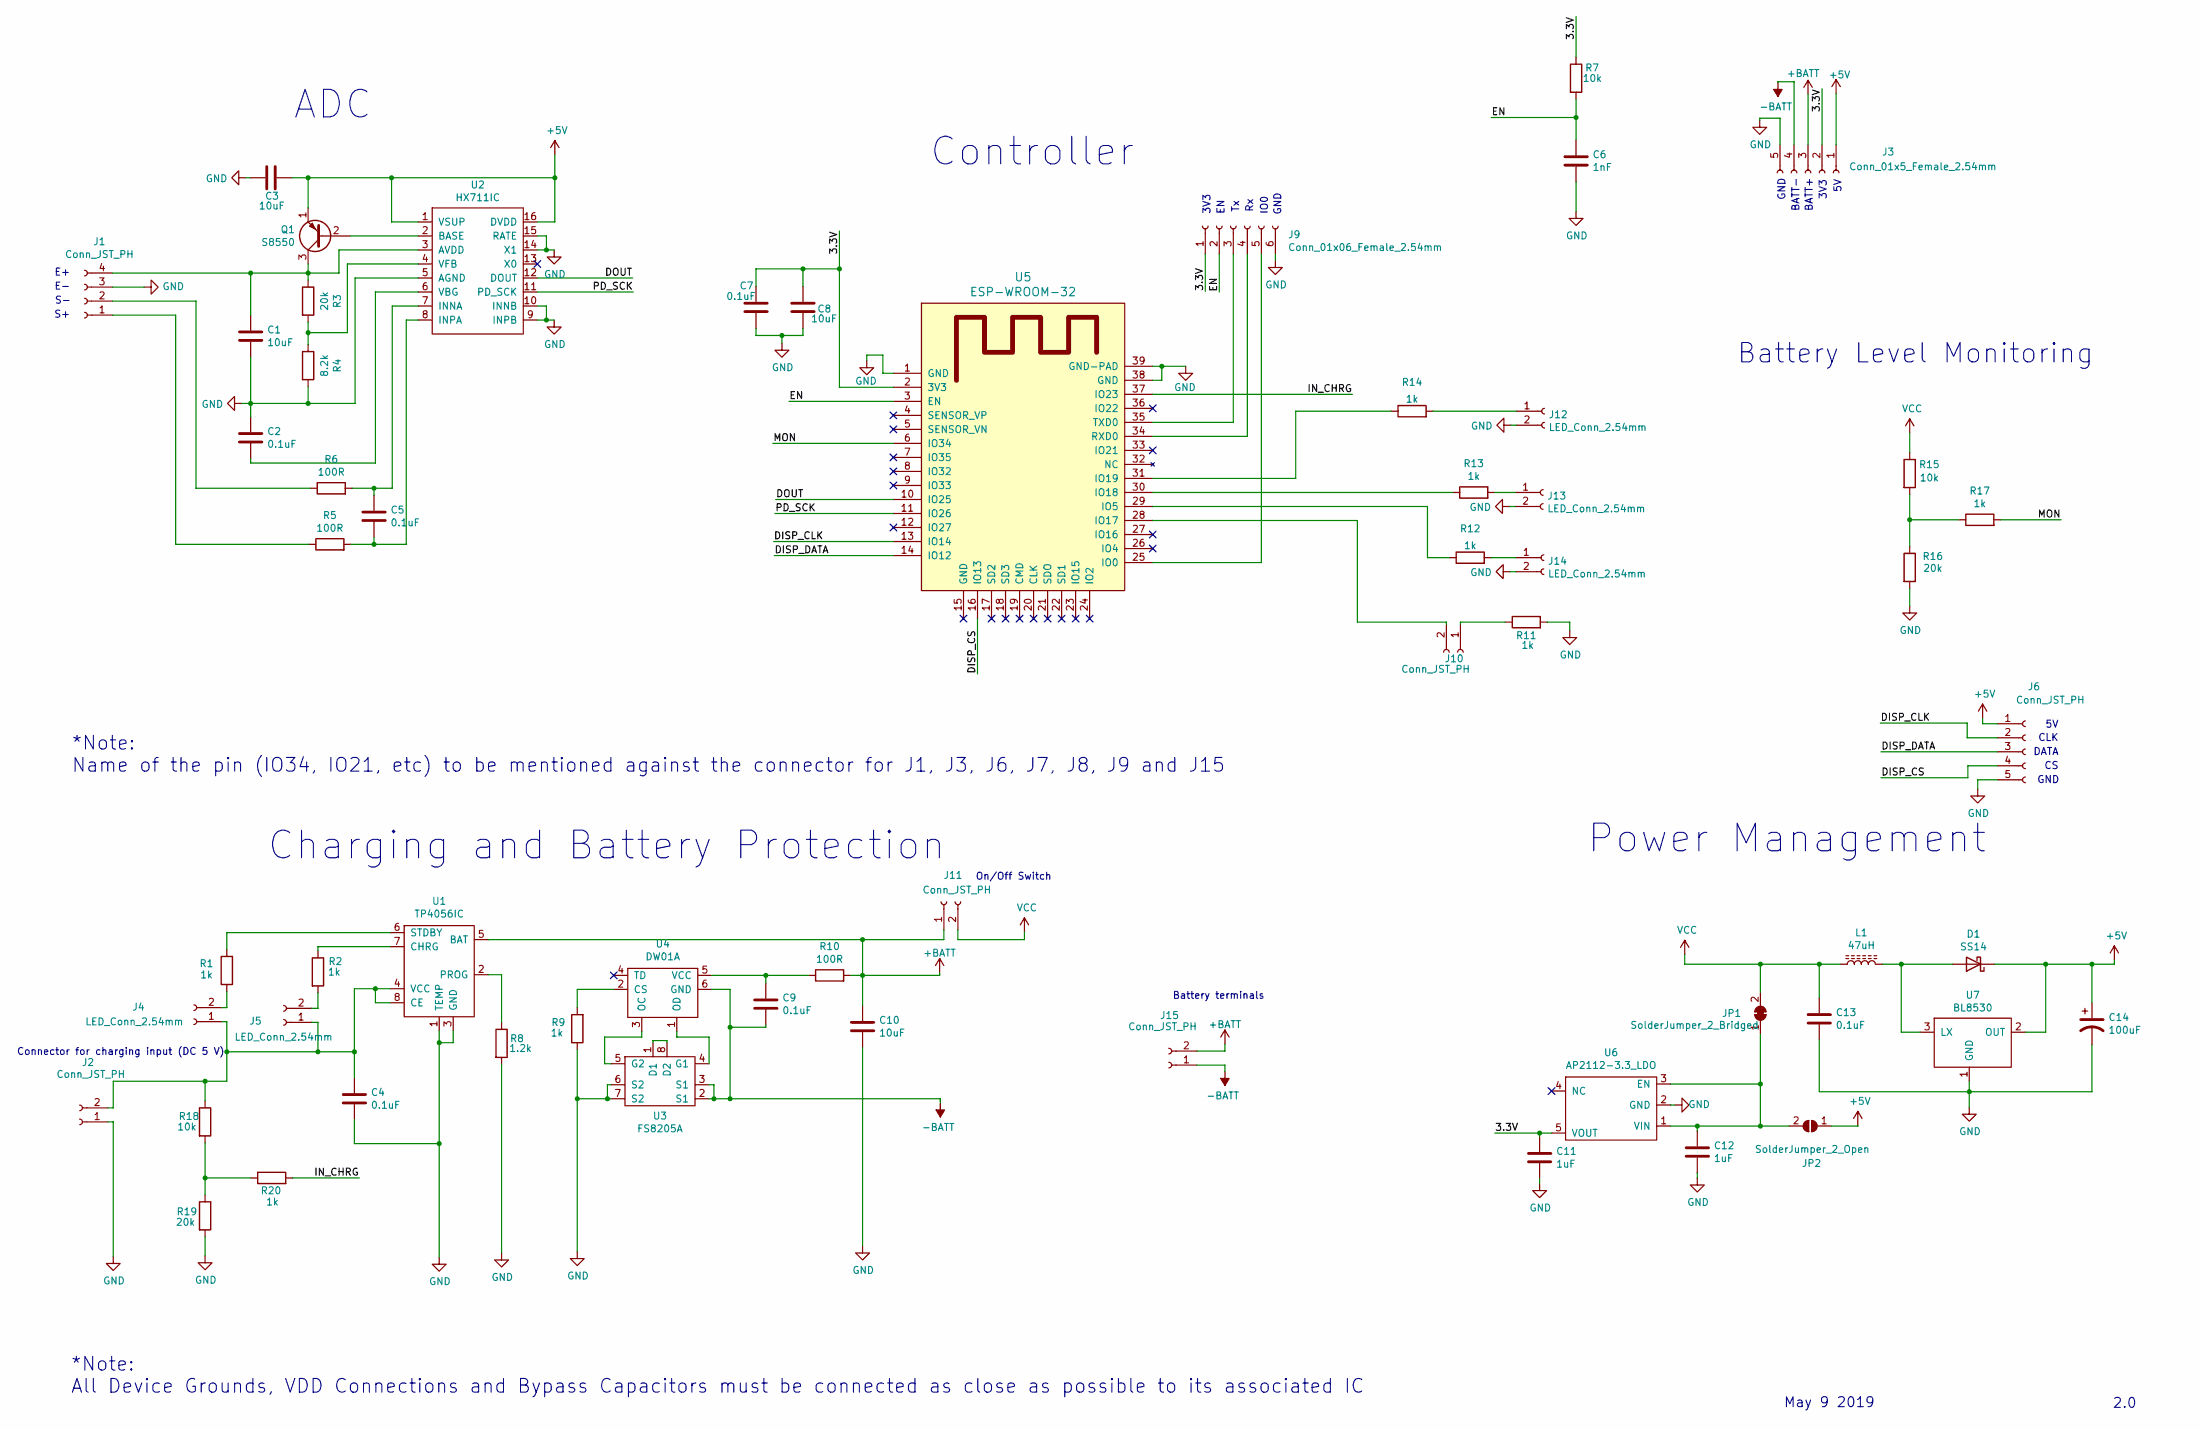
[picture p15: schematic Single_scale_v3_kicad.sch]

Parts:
C1, C3, C8, C10: 10uF; C_0603_1608Metric
C2, C4, C5, C7, C9, C13: 0.1uF; C_0603_1608Metric
C6: 1nF; C_0603_1608Metric
C11, C12: 1uF; C_0603_1608Metric
C14: 100uF; CP_Elec_6.3x5.4
D1: SS14; D_SMA
J1: Conn_JST_PH; JST_PH_B4B-PH-K_1x04_P2.00mm_Vertical
J2, J10, J11, J15: Conn_JST_PH; JST_EH_B2B-EH-A_1x02_P2.50mm_Vertical
J3: Conn_01x5_Female_2.54mm; PinHeader_1x05_P2.54mm_Vertical
J4, J5, J12, J13, J14: LED_Conn_2.54mm; PinHeader_1x02_P2.54mm_Vertical
J6: Conn_JST_PH; JST_PH_B5B-PH-K_1x05_P2.00mm_Vertical
J9: Conn_01x06_Female_2.54mm; PinHeader_1x06_P2.54mm_Vertical
JP1: SolderJumper_2_Bridged; SolderJumper-2_P1.3mm_Bridged2Bar_Pad1.0x1.5mm
JP2: SolderJumper_2_Open; SolderJumper-2_P1.3mm_Open_Pad1.0x1.5mm
L1: 47uH; L_Taiyo-Yuden_MD-5050
Q1: S8550; SOT-23_modified
R1, R2, R9, R11, R12, R13, R14, R17, R20: 1k; R_0603_1608Metric
R3, R16, R19: 20k; R_0603_1608Metric
R4: 8.2k; R_0603_1608Metric
R5, R6, R10: 100R; R_0603_1608Metric
R7, R15, R18: 10k; R_0603_1608Metric
R8: 1.2k; R_0603_1608Metric
U1: TP4056IC; SOP-8
U2: HX711IC; SOP-16_4.55x10.3mm_P1.27mm
U3: FS8205A; TSSOP-8_4.4x3mm_P0.65mm
U4: DW01A; SOT-23-6
U5: ESP-WROOM-32; MODULE_ESP32-WROOM-32
U6: AP2112-3.3_LDO; SOT-23-5
U7: BL8530; SOT-89-3

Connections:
+5V: C3.1, C14.1, D1.1 (K), J3.1, J6.1, JP2.1 (A), Q1.1 (E), U2.1 (VSUP), U2.16 (DVDD), U7.2 (OUT)
+BATT: C10.1, J3.3, J11.1, J15.2, R10.2, U1.5 (BAT)
-BATT: C9.2, J3.4, J15.1, U3.2 (S1), U3.3 (S1), U4.6 (GND)
/3.3V: C7.1, C8.1, C11.1, J3.2, J9.1, R7.1, U5.2 (3V3), U6.5 (VOUT)
/DISP_CLK: J6.2, U5.13 (IO14)
/DISP_CS: J6.4, U5.16 (IO13)
/DISP_DATA: J6.3, U5.14 (IO12)
/DOUT: U2.12 (DOUT), U5.10 (IO25)
/EN: C6.1, J9.2, R7.2, U5.3 (EN)
/IN_CHRG: R20.2, U5.37 (IO23)
/MON: R17.2, U5.6 (IO34)
/PD_SCK: U2.11 (PD_SCK), U5.11 (IO26)
GND: C1.2, C2.1, C3.2, C4.2, C6.2, C7.2, C8.2, C10.2, C11.2, C12.2, C13.2, C14.2, J1.3, J2.1, J3.5, J6.5, J9.6, J12.2, J13.2, J14.2, R4.2, R8.2, R9.1, R11.2, R16.2, R19.2, U1.1 (TEMP), U1.3 (GND), U2.5 (AGND), U2.9 (INPB), U2.10 (INNB), U2.14 (X1), U2.15 (RATE), U3.6 (S2), U3.7 (S2), U5.1 (GND), U5.38 (GND), U5.39 (GND-PAD), U6.2 (GND), U7.1 (GND)
unnamed: C1.1, J1.4, Q1.3 (C), R3.1, U2.3 (AVDD)
unnamed: C2.2, U2.6 (VBG)
unnamed: C4.1, J2.2, J4.1, J5.1, R18.1, U1.4 (VCC), U1.8 (CE)
unnamed: C5.1, R6.2, U2.7 (INNA)
unnamed: C5.2, R5.2, U2.8 (INPA)
unnamed: C9.1, R10.1, U4.5 (VCC)
unnamed: C12.1, JP1.1 (A), JP2.2 (B), U6.1 (VIN), U6.3 (EN)
unnamed: D1.2 (A), L1.2, U7.3 (LX)
unnamed: J1.1, R5.1
unnamed: J1.2, R6.1
unnamed: J4.2, R1.1
unnamed: J5.2, R2.2
unnamed: J9.3, U5.35 (TXD0)
unnamed: J9.4, U5.34 (RXD0)
unnamed: J9.5, U5.25 (IO0)
unnamed: J10.1, R11.1
unnamed: J10.2, U5.28 (IO17)
unnamed: J12.1, R14.2
unnamed: J13.1, R13.2
unnamed: J14.1, R12.2
unnamed: Q1.2 (B), U2.2 (BASE)
unnamed: R1.2, U1.6 (STDBY)
unnamed: R2.1, U1.7 (CHRG)
unnamed: R3.2, R4.1, U2.4 (VFB)
unnamed: R8.1, U1.2 (PROG)
unnamed: R9.2, U4.2 (CS)
unnamed: R12.1, U5.29 (IO5)
unnamed: R13.1, U5.30 (IO18)
unnamed: R14.1, U5.31 (IO19)
unnamed: R15.2, R16.1, R17.1
unnamed: R18.2, R19.1, R20.1
unnamed: U3.1 (D1), U3.8 (D2)
unnamed: U3.4 (G1), U4.1 (OD)
unnamed: U3.5 (G2), U4.3 (OC)
VCC: C13.1, J11.2, JP1.2 (B), L1.1, R15.1

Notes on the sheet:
Charging and Battery Protection
Power Management
ADC
Battery Level Monitoring
Controller
May 9 2019
2.0
*Note: All Device Grounds, VDD Connections and Bypass Capacitors must be connected as close as possible to its associated IC
*Note: Name of the pin (IO34, IO21, etc) to be mentioned against the connector for J1, J3, J6, J7, J8, J9 and J15
GND
BATT-
BATT+
3V3
IO0
DATA
CLK
Connector for charging input (DC 5 V)
Battery terminals
On/Off Switch

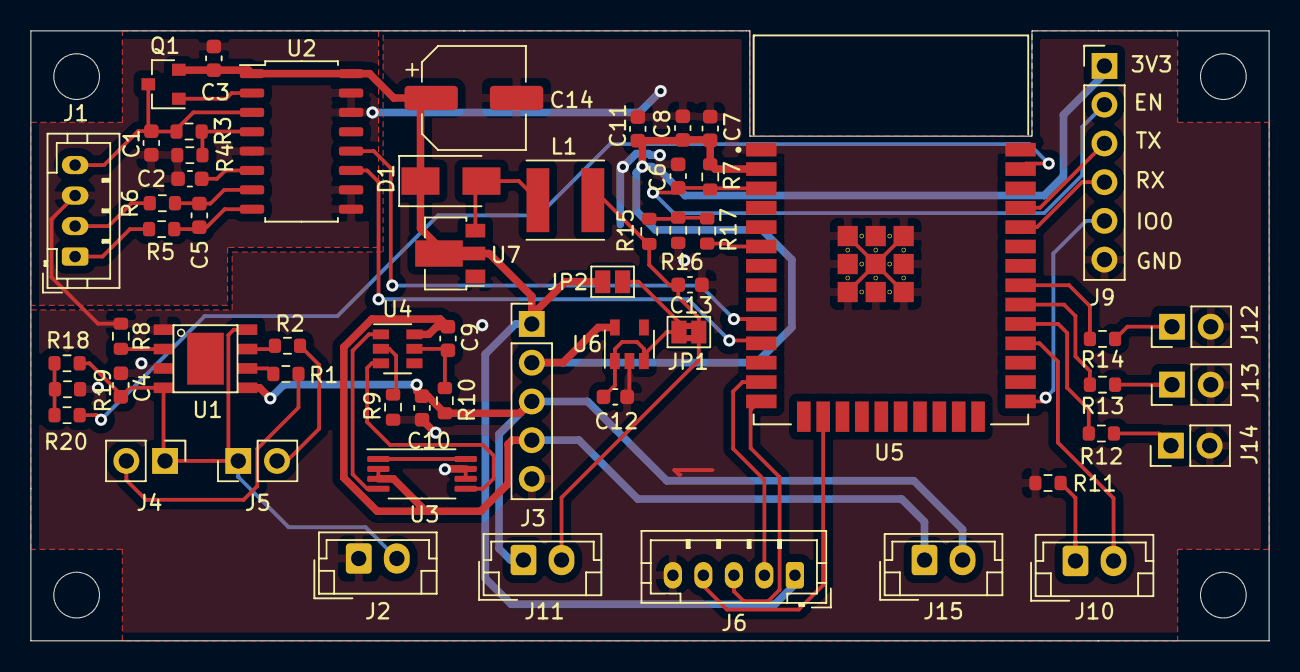
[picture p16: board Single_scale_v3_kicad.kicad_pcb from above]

Board: 2 copper layers, 81.2 x 40.0 mm, 59 parts (0 on the bottom side), 48 nets.

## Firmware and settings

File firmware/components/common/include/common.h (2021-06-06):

//
//  common.h
//  Weighing_Scale_Firmware
//
//  ESP32 firmware for Smart Weighing Scale
//
//  This module provides functions and queues to pass data between other modules.
//
//  Created by IoTReady Technology Solutions Pvt. Ltd., Bangalore
//  Copyright © 2019 IoTReady Technology Solutions Pvt. Ltd., Bangalore
//
// All rights reserved. Gaining access to this code without explicit 
// license or through reverse compilation constitutes violation of 
// protected intellectual property rights.
// 
// If you are interested in using this code or similar functionality
// for your product, please contact us at hello@iotready.co
//
// Unless required by applicable law or agreed to in writing, software
// distributed under the License is distributed on an "AS IS" BASIS,
// WITHOUT WARRANTIES OR CONDITIONS OF ANY KIND, either express or implied.
// See the License for the specific language governing permissions and
// limitations under the License.
//

#ifndef __COMMON_H__
#define __COMMON_H__ 1

#include "freertos/FreeRTOS.h"
#include "freertos/queue.h"
#include "freertos/task.h"
#include "wifi_sta.h" 

// Used by the OTA module to check if the current version is different from the version
// on the server, i.e. if an upgrade or downgrade should be performed.
#define SOFTWARE_VERSION          0

// Provide the network name and password of your WIFI network.
#define DEFAULT_WIFI_SSID         "myssid"
#define DEFAULT_WIFI_PASSWORD     "mypassword"
#define DEFAULT_TIMEOUT 10 //ticks = 100ms

// Default user preferences
#define DEFAULT_LIGHT_MODE 2 // combo
#define DEFAULT_SESSION_TIME 10 // minutes
#define DEFAULT_PAUSE_LIMIT 30 // minutes
#define DEFAULT_COOLING_PERIOD 5 // minutes
#define MAX_SYSTEM_TEMPERATURE 50 // celcius

#define DEFAULT_BLE_NAME "IOTReadyScale"

// Priorities
#define LOW_PRIORITY 5
#define MEDIUM_PRIORITY 10


// Stack sizes

#define LARGEST_STACK 15360
#define LARGER_STACK 8192
#define LARGE_STACK 4096
#define MEDIUM_STACK 2048
#define SMALL_STACK 1024

#define LINK_MODE_FOLLOW 1
#define LINK_MODE_LEAD 2
#define LINK_MODE_NEUTRAL 3

// Provide server name, path to metadata file and polling interval for OTA updates.
#define OTA_SERVER_HOST_NAME      "galtofkgp.github.io"
#define OTA_SERVER_METADATA_PATH  "/esp32/ota.txt"
#define OTA_POLLING_INTERVAL_S    60
#define OTA_AUTO_REBOOT           1

// Provide the Root CA certificate for chain validation.
// (copied from browser certificates for https://galtofkgp.github.io)
#define OTA_SERVER_ROOT_CA_PEM \
    "-----BEGIN CERTIFICATE-----\n" \
    "MIIDxTCCAq2gAwIBAgIQAqxcJmoLQJuPC3nyrkYldzANBgkqhkiG9w0BAQUFADBs\n" \
    "MQswCQYDVQQGEwJVUzEVMBMGA1UEChMMRGlnaUNlcnQgSW5jMRkwFwYDVQQLExB3\n" \
    "d3cuZGlnaWNlcnQuY29tMSswKQYDVQQDEyJEaWdpQ2VydCBIaWdoIEFzc3VyYW5j\n" \
    "ZSBFViBSb290IENBMB4XDTA2MTExMDAwMDAwMFoXDTMxMTExMDAwMDAwMFowbDEL\n" \
    "MAkGA1UEBhMCVVMxFTATBgNVBAoTDERpZ2lDZXJ0IEluYzEZMBcGA1UECxMQd3d3\n" \
    "LmRpZ2ljZXJ0LmNvbTErMCkGA1UEAxMiRGlnaUNlcnQgSGlnaCBBc3N1cmFuY2Ug\n" \
    "RVYgUm9vdCBDQTCCASIwDQYJKoZIhvcNAQEBBQADggEPADCCAQoCggEBAMbM5XPm\n" \
    "+9S75S0tMqbf5YE/yc0lSbZxKsPVlDRnogocsF9ppkCxxLeyj9CYpKlBWTrT3JTW\n" \
    "PNt0OKRKzE0lgvdKpVMSOO7zSW1xkX5jtqumX8OkhPhPYlG++MXs2ziS4wblCJEM\n" \
    "xChBVfvLWokVfnHoNb9Ncgk9vjo4UFt3MRuNs8ckRZqnrG0AFFoEt7oT61EKmEFB\n" \
    "Ik5lYYeBQVCmeVyJ3hlKV9Uu5l0cUyx+mM0aBhakaHPQNAQTXKFx01p8VdteZOE3\n" \
    "hzBWBOURtCmAEvF5OYiiAhF8J2a3iLd48soKqDirCmTCv2ZdlYTBoSUeh10aUAsg\n" \
    "EsxBu24LUTi4S8sCAwEAAaNjMGEwDgYDVR0PAQH/BAQDAgGGMA8GA1UdEwEB/wQF\n" \
    "MAMBAf8wHQYDVR0OBBYEFLE+w2kD+L9HAdSYJhoIAu9jZCvDMB8GA1UdIwQYMBaA\n" \
    "FLE+w2kD+L9HAdSYJhoIAu9jZCvDMA0GCSqGSIb3DQEBBQUAA4IBAQAcGgaX3Nec\n" \
    "nzyIZgYIVyHbIUf4KmeqvxgydkAQV8GK83rZEWWONfqe/EW1ntlMMUu4kehDLI6z\n" \
    "eM7b41N5cdblIZQB2lWHmiRk9opmzN6cN82oNLFpmyPInngiK3BD41VHMWEZ71jF\n" \
    "hS9OMPagMRYjyOfiZRYzy78aG6A9+MpeizGLYAiJLQwGXFK3xPkKmNEVX58Svnw2\n" \
    "Yzi9RKR/5CYrCsSXaQ3pjOLAEFe4yHYSkVXySGnYvCoCWw9E1CAx2/S6cCZdkGCe\n" \
    "vEsXCS+0yx5DaMkHJ8HSXPfqIbloEpw8nL+e/IBcm2PN7EeqJSdnoDfzAIJ9VNep\n" \
    "+OkuE6N36B9K\n" \
    "-----END CERTIFICATE-----\n"

// Provide the Peer certificate for certificate pinning.
// (copied from browser certificates for https://galtofkgp.github.io)
#define OTA_PEER_PEM \
    "-----BEGIN CERTIFICATE-----\n" \
    "MIIHMTCCBhmgAwIBAgIQDf56dauo4GsS0tOc8/ik/DANBgkqhkiG9w0BAQsFADBw\n" \
    "MQswCQYDVQQGEwJVUzEVMBMGA1UEChMMRGlnaUNlcnQgSW5jMRkwFwYDVQQLExB3\n" \
    "d3cuZGlnaWNlcnQuY29tMS8wLQYDVQQDEyZEaWdpQ2VydCBTSEEyIEhpZ2ggQXNz\n" \
    "dXJhbmNlIFNlcnZlciBDQTAeFw0xODA2MjcwMDAwMDBaFw0yMDA2MjAxMjAwMDBa\n" \
    "MGoxCzAJBgNVBAYTAlVTMRMwEQYDVQQIEwpDYWxpZm9ybmlhMRYwFAYDVQQHEw1T\n" \
    "YW4gRnJhbmNpc2NvMRUwEwYDVQQKEwxHaXRIdWIsIEluYy4xFzAVBgNVBAMTDnd3\n" \
    "dy5naXRodWIuY29tMIIBIjANBgkqhkiG9w0BAQEFAAOCAQ8AMIIBCgKCAQEAxjbK\n" \
    "Rw+cVNjgA/BhLfRTOAk6jRGT7WRmmWy/qhFmTxBKapW/Kh4UNeD7oUAB0yG+Fyvu\n" \
    "1grVYR5RFUGBmA5mkqrBjCg4fNbFU9vLKIbkhpH3Jp2HVNLzvjzs/RqCN04MEc6M\n" \
    "nbmkjx1YeW9CveXojrt4x3Sa3nsPx6KcQtJpm8MuS8OhV2CJUF1etJpu9id5WJQd\n" \
    "U3j3h65PmXMBvunm7UaGDt2WVK4CRcIb6j0X3H4cjh4WhXLyMcSPutXZVoD0FSmY\n" \
    "+mjXVZCTJd+vHsYX1fj+kge20DJx0F8qmqJEr7bx1lfj7/U4aTgdZBDCB8wIl0fK\n" \
    "cOdR3wq2RrDVRUlOuQIDAQABo4IDyzCCA8cwHwYDVR0jBBgwFoAUUWj/kK8CB3U8\n" \
    "zNllZGKiErhZcjswHQYDVR0OBBYEFI+I3Dwd7kQJ5DCMBsoC859olPB5MHsGA1Ud\n" \
    "EQR0MHKCDnd3dy5naXRodWIuY29tggsqLmdpdGh1Yi5pb4IXKi5naXRodWJ1c2Vy\n" \
    "Y29udGVudC5jb22CDCouZ2l0aHViLmNvbYIKZ2l0aHViLmNvbYIJZ2l0aHViLmlv\n" \
    "ghVnaXRodWJ1c2VyY29udGVudC5jb20wDgYDVR0PAQH/BAQDAgWgMB0GA1UdJQQW\n" \
    "MBQGCCsGAQUFBwMBBggrBgEFBQcDAjB1BgNVHR8EbjBsMDSgMqAwhi5odHRwOi8v\n" \
    "Y3JsMy5kaWdpY2VydC5jb20vc2hhMi1oYS1zZXJ2ZXItZzYuY3JsMDSgMqAwhi5o\n" \
    "dHRwOi8vY3JsNC5kaWdpY2VydC5jb20vc2hhMi1oYS1zZXJ2ZXItZzYuY3JsMEwG\n" \
    "A1UdIARFMEMwNwYJYIZIAYb9bAEBMCowKAYIKwYBBQUHAgEWHGh0dHBzOi8vd3d3\n" \
    "LmRpZ2ljZXJ0LmNvbS9DUFMwCAYGZ4EMAQICMIGDBggrBgEFBQcBAQR3MHUwJAYI\n" \
    "KwYBBQUHMAGGGGh0dHA6Ly9vY3NwLmRpZ2ljZXJ0LmNvbTBNBggrBgEFBQcwAoZB\n" \
    "aHR0cDovL2NhY2VydHMuZGlnaWNlcnQuY29tL0RpZ2lDZXJ0U0hBMkhpZ2hBc3N1\n" \
    "cmFuY2VTZXJ2ZXJDQS5jcnQwDAYDVR0TAQH/BAIwADCCAX4GCisGAQQB1nkCBAIE\n" \
    "ggFuBIIBagFoAHYA7ku9t3XOYLrhQmkfq+GeZqMPfl+wctiDAMR7iXqo/csAAAFk\n" \
    "QsgYsgAABAMARzBFAiBe00KrPC3L9DUwJ0rYXoQ+Fh70UM3rYNyT9uLyEo1kfAIh\n" \
    "ALtR7krXouwsj4s52P2bWJiS0QKGLvbnBGnZLn4WNScDAHYAh3W/51l8+IxDmV+9\n" \
    "827/Vo1HVjb/SrVgwbTq/16ggw8AAAFkQsgYswAABAMARzBFAiB2wURHjtfhDN6l\n" \
    "3Q9gaYnu9h5xsFjJIOA3qO1dzqNVjQIhANPyeXq61y1gsHH/Iq2aqv43CMjjDQ8p\n" \
    "02baNg3puNoMAHYAu9nfvB+KcbWTlCOXqpJ7RzhXlQqrUugakJZkNo4e0YUAAAFk\n" \
    "QsgX9wAABAMARzBFAiEAhxuoQCyQzEoSK8/f4AXq+d0RZ3550opfcEty3p7gHyAC\n" \
    "IBZ3NXHCNZpH6ow7D/qUZcfXkuMk/aZvR9uHoVvkixbcMA0GCSqGSIb3DQEBCwUA\n" \
    "A4IBAQCjPNhowM6/PVcxHtl18r+92pPzU3JRGnXfz/P077yEgIIgs8I0lPqi9AiW\n" \
    "QYev56+Ar4a39y+666s55ogjIVL+7cboKPgqflEY1POCg64UZNDHHPTnd5ba2OUw\n" \
    "dtk1QtrEtYbUKm0W/1Ne9JRdN2rh5J87NsSPhirmKsP6HA3OhL93LTqB72Iehwj+\n" \
    "qmIrQhkhJiTReWTb5sNrD2gIt8Dhuts/M84a9v7Hrkq/VPYVmARm7Py0GC/jqxpI\n" \
    "NCHBEAFKN2c7iqmx1dVOGJDV3U0TCa0yWbnXsZ9M0652zH1obM3UxCtUMuUZzDb9\n" \
    "aTrrJ67dru040mysq2NLPPq+t+EQ\n" \
    "-----END CERTIFICATE-----\n"

// -------------------------------------------------------------------------------------


wifi_sta_init_struct_t wifi_params;
uint8_t weight_data; 
extern int boot_mode;
bool just_booted;
bool allow_reboot;
extern char device_id[13];
extern char OTA_IP[100];
extern char OTA_PORT[100];
extern char OTA_FILENAME[100];
extern float Totalmass;
extern char TotalmassStr[16];

// TaskHandle_t weighingTask_Handle, tareTask_Handle;


// functions

void set_device_id();
#endif // __COMMON_H__

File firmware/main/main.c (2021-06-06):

//
//  main.c
//  Weighing_Scale_Firmware
//
//  ESP32 firmware for Smart Weighing Scale
// 
//  This is the main file for Weighing_Scale_Firmware.
//
//  Created by IoTReady Technology Solutions Pvt. Ltd., Bangalore
//  Copyright © 2019 IoTReady Technology Solutions Pvt. Ltd., Bangalore
//
// All rights reserved. Gaining access to this code without explicit 
// license or through reverse compilation constitutes violation of 
// protected intellectual property rights.
// 
// If you are interested in using this code or similar functionality
// for your product, please contact us at hello@iotready.co
//
// Unless required by applicable law or agreed to in writing, software
// distributed under the License is distributed on an "AS IS" BASIS,
// WITHOUT WARRANTIES OR CONDITIONS OF ANY KIND, either express or implied.
// See the License for the specific language governing permissions and
// limitations under the License.
//

#include "HX711.h"
#include "weighing_scale.h"
#include <stdio.h>
#include "freertos/FreeRTOS.h"
#include "freertos/task.h"
#include "esp_system.h"
#include "esp_spi_flash.h"
#include "console_lib.h"
#include "ble_lead.h"
#include "ble_common.h"
#include "common.h"
#include "esp_log.h"
#include "nvs_store.h"
#include "esp_event_loop.h"
#include "driver/gpio.h"
#include "battery_level_check.h"

#define TAG "main"

// #define BUTTON_GPIO 19


static esp_err_t app_event_handler(void *ctx, system_event_t *event);

void app_main()
{   
    esp_err_t err;

    /* Get the device MAC ID */
    set_device_id();

    vTaskDelay(100/portTICK_PERIOD_MS);

    /* Initialize Non-volatile Storage */
    init_nvs();

    // Init Display and display "HELLO . . ." until weighing scale init is completed
    initDisplay();

    /* WiFi */
    // err = read_wifi_params_nvs();
    // if (err)
    // {
    //     write_wifi_params_nvs();
    // }

    /* Initialize Wi-Fi event handler */    
    esp_event_loop_init(&app_event_handler, NULL);

    /* Initialize BLE */
    init_ble();

    /* Register BLE characteristics, services and callbacks */    
    enable_ble_lead();

    vTaskDelay(100/portTICK_PERIOD_MS);
    
    /* Initialize Weighing Scale */
    init_weighingScale();

    /* Set value to zero on initialization and write it to NVS */
    tare(5);
    write_offset_nvs();

    /* Check battery level at initialization */
    battery();

    /* Initialize console UART to tare and calibrate through keyboard */    
    initialize_console();

    ESP_LOGI(TAG,"OFFSET: %ld \n", OFFSET);
    ESP_LOGI(TAG,"SCALE: %ld \n", SCALE);
    
    /* Initialize weighing task */
    xTaskCreatePinnedToCore(&weighingTask, "weighingTask", 8192, NULL, 7, &weighingTask_Handle, APP_CPU_NUM);
    /* Watch tare button to tare weight to zero */
    xTaskCreate(&tareTask, "tareTask", 3 * 1024, NULL, 5, &tareTask_Handle);
    /* Initialize task to monitor battery level */
    xTaskCreate(&battery_level_check_task, "battery_level_check_task", 3 * 1024, NULL, LOW_PRIORITY, &battery_level_check_task_handle);
    /* Initialize console UART task for calibration and Tare */
    xTaskCreate(&run_console, "run_console", 4 * 1024, NULL, 5, NULL);


    // wifi_sta_init(&wifi_params);
    
}


/* Wi-Fi event handler */
static esp_err_t app_event_handler(void *ctx, system_event_t *event)
{
    esp_err_t result = ESP_OK;
    int handled = 0;
    
    ESP_LOGI(TAG, "app_event_handler: event: %d", event->event_id);

    /* Let the wifi_sta module handle all WIFI STA events */
    
    result = wifi_sta_handle_event(ctx, event, &handled);
    if (ESP_OK != result || handled) {
        return result;
    }
        
    ESP_LOGW(TAG, "app_event_handler: unhandled event: %d", event->event_id);
    return ESP_OK;
}
